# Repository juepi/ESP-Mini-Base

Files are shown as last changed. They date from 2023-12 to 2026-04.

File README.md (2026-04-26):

# ESP-Mini-Base
Base PCB ("hat") for ESP boards in WEMOS Mini format created with [KiCad EDA](https://www.kicad.org/). Primarily designed for [WEMOS S2 Mini](https://www.wemos.cc/en/latest/s2/s2_mini.html) and [D1 Mini](https://www.wemos.cc/en/latest/d1/d1_mini.html), might work for others / upcoming boards with a compatible pinout.  
The schematic describes the functionality and options in detail, it is also [available as PDF](pdf/ESP-Mini-Base_v1.0_schematic.pdf).

## Available functionality

The board provides the following functions:

* 3x N-Channel MOSFET drains (20A / 20Vds; no more than 5A recommended)
* 1x AC/DC SSR (48Vpp, 500mA max.)
* 1x Supply switch (5V or 3.3V, 2A max.)
* 2x 4-channel Level shifters to 5V
* 1x ADC attenuator with input selection (3V3 rail, 5V rail or external pin)
* 1x Pushbutton
* 3V3 and 5V I2C Pullups for default I2C pins of S2 and D1 Mini
* 5V LDO linear regulator for power supply up to 12V

The board has been designed in a way to allow you maximum flexibility. Every function needs to be enabled via solder jumpers on the bottom PCB side (for default wiring), or you may wire different IOs to the according pin headers on the board.  
The only exclusion are the 8 IOs wired to the 2 level shifters, which are hard wired and cannot be changed. The IOs have been selected to allow you level-shifted SPI or I2C for both S2 and D1 boards.

## Power Supply

There are several ways to power the board, the following table shows you the options and required configuration (solder jumpers on bottom PCB side):

| Powered by | Short Solder Jumpers | Notes |
| --- | --- | --- |
| 5V/VBUS Pin or USB Port | JP12 | Not recommended for MOSFET usage! At least connect GND wire to J9 if you try to do so|
| "12VDC" through J9 | JP12,JP13 | 5V generated from onboard regulator and supplied to ESP. Supported input voltage range: between 6.25 and 12V|
| 3.3VDC through J9 | none | Use to power ESP directly from LFP battery (in example)|

When powering the board from a LFP cell, you might want to have 5VDC (in example for a LED strip). Mainly for this reason, you have the ability to connect a Boost-converter board to J10. Short the Jumper JP11 and JP10 to 1-2 and you will be able to enable the Boost-converter via IO14 (U2 supply switch).  
Although the installed 5V LDO linear regulator supports up to 26V input voltage, no more than 12V are recommended due to the high power dissipation of the regulator.  

## Note on production data

The production data has been created for [JLCPCB assembly service](https://jlcpcb.com/) using the [Fabrication Toolkit Plugin](https://github.com/bennymeg/JLC-Plugin-for-KiCad). When placing an order, keep in mind that the rotation of several parts (MOSFETs, all ICs, C6) needs to be updated. Cross-check with the KiCAD Layout to verify that all parts will be placed correctly.

## Note on MOSFET usage

If you are switching a device through one of the 3 installed N-Channel MOSFETs, make sure that the switched device does **not have any reference to the input voltage GND** of the ESP-Mini-Base (in example through a data connection like I2C etc.). Chances are high to see magic smoke leaving your setup if you fail to use suitable galvanic isolation (beside the fact that the "switched" device probably won't power off at all)!
The MOSFETs have been tested fine with 5kHz PWM, so they should work for dimming RGB LED strips in example. Keep an eye on the overall current running through the FETs, more than 5A should be tested thoroughly before placing it into production.
  
## Pictures

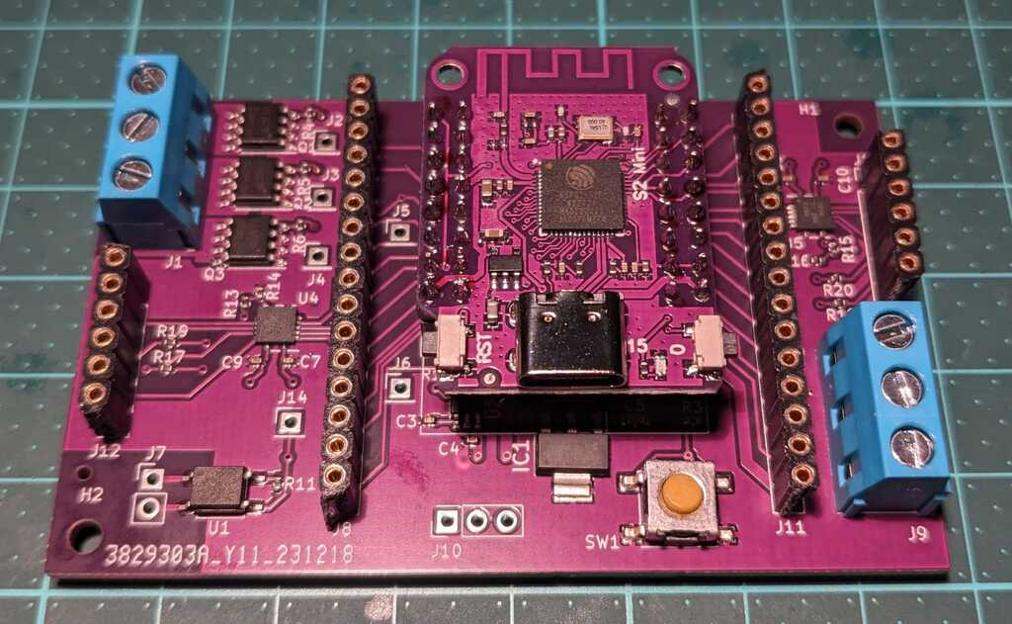
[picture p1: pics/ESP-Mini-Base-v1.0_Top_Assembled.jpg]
Assembled PCB, top side

Assembled ESP-Mini-Base v1.0 top side with S2 Mini  

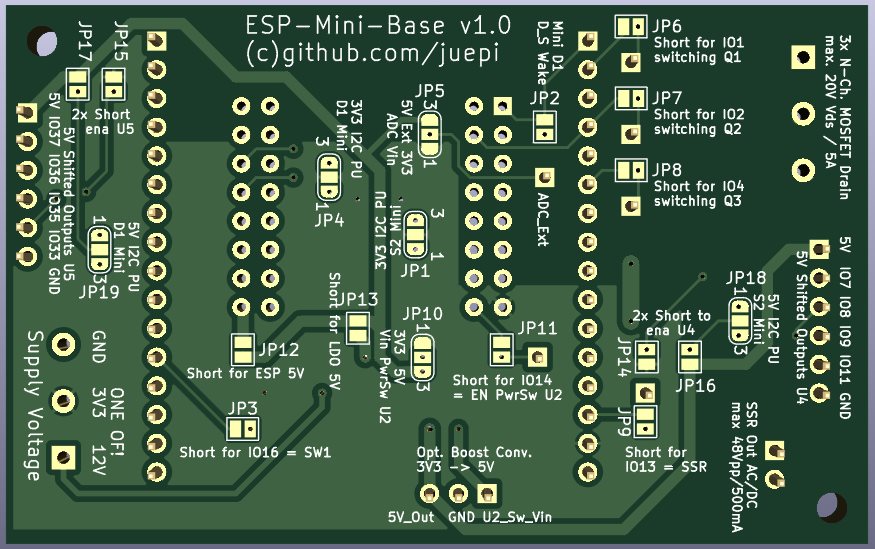
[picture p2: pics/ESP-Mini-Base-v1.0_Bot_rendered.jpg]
Rendered PCB, bottom side

Rendered view of the bottom side showing I/O and solder jumpers with descriptions.

**Note on I2C Pullup solder-jumpers (3,3 and 5V):** all 3 pins of the jumpers need to be connected with tin solder if you want to enable the pullups.

## ESPHome
Added sample ESPHome YAML config which uses most of the functionality provided by the ESP-Mini-Base. The sample is intended to be used with the `WEMOS S2 Mini` board.  
**Note on first wired flash:** The web based flashing with ESPHome did not work for me with the `WEMOS S2 Mini`. I had to download the compiled binary firmware and then used the [Adafruit WebSerial ESPTool](https://adafruit.github.io/Adafruit_WebSerial_ESPTool/) which managed to flash the ESP board correctly. Subsequent OTA updates worked perfectly well with ESPHome.

## Changelog

### v1.1
- Improved high current traces to MOSFETs
- Improved heat dissipation of LDO converter (IC1)
- Upgraded KiCAD files to version 8
- Set "remove from BoM" flag on all THT parts and solder jumpers

Have fun,  
Juergen

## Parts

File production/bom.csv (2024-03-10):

Designator | Footprint | Quantity | Value | LCSC Part #
C1, C10, C4, C7, C8, C9 | 0402 | 6 | 100n/25V | C106256
C2 | 0402 | 1 | 1µ/25V | C967571
C3 | 0402 | 1 | 1n/25V | C575438
C5 | 0603 | 1 | 470nF/50V | C77572
C6 | CP_EIA-7343-31_Kemet-D | 1 | 100µF/16V | C171666
H1, H2 | MountingHole_2.7mm_M2.5 | 2 | MountingHole
IC1 | SOT230P700X180-4N | 1 | LM2940IMP-5.0_NOPB | C13991
J1, J9 | TerminalBlock_RND_205-00046_1x03_P5.00mm_Horizontal | 2 | Screw_Terminal_01x03
J10 | PinHeader_1x03_P2.54mm_Vertical | 1 | Conn_01x03
J11, J8 | PinHeader_1x16_P2.54mm_Vertical | 2 | Conn_01x16
J12, J13 | PinHeader_1x06_P2.54mm_Vertical | 2 | Conn_01x06
J14, J2, J3, J4, J5, J6 | PinHeader_1x01_P2.54mm_Vertical | 6 | ~
J7 | PinHeader_1x02_P2.54mm_Vertical | 1 | Conn_01x02
JP1, JP10, JP18, JP19, JP4, JP5 | SolderJumper-3_P1.3mm_Open_RoundedPad1.0x1.5mm_NumberLabels | 6 | SolderJumper_3_Open
JP11, JP12, JP13, JP14, JP15, JP16, JP17, JP2, JP3, JP6, JP7, JP8, JP9 | SolderJumper-2_P1.3mm_Open_Pad1.0x1.5mm | 13
Q1, Q2, Q3 | SOIC-8_3.9x4.9mm_P1.27mm | 3 | AO4402G | C2931062
R1, R2, R7, R8 | 0402 | 4 | 3k3 | C965263
R10 | 0402 | 1 | 3k6/0.1% | C186338
R11 | 0402 | 1 | 220 | C102889
R12, R3, R4, R5, R6 | 0402 | 5 | 10k | C25744
R13, R15 | 0402 | 2 | 931 | C35293
R14, R16 | 0402 | 2 | 1k8 | C170383
R17, R18, R19, R20 | 0402 | 4 | 4k7 | C25900
R9 | 0402 | 1 | 12k/0.1% | C186350
SW1 | SW_Push_1P1T_NO_6x6mm_H9.5mm | 1 | SW_Omron_B3FS | C271751
U1 | SOP-4_3.8x4.1mm_P2.54mm | 1 | G3VM-61VY2 | C1558855
U2 | SOT-23-6 | 1 | TPS22918DBVR | C131941
U3 | WEMOS_S2_Mini | 1 | S2 Mini
U4, U5 | Texas_S-PVQFN-N14 | 2 | TXB0104RGY | C400708

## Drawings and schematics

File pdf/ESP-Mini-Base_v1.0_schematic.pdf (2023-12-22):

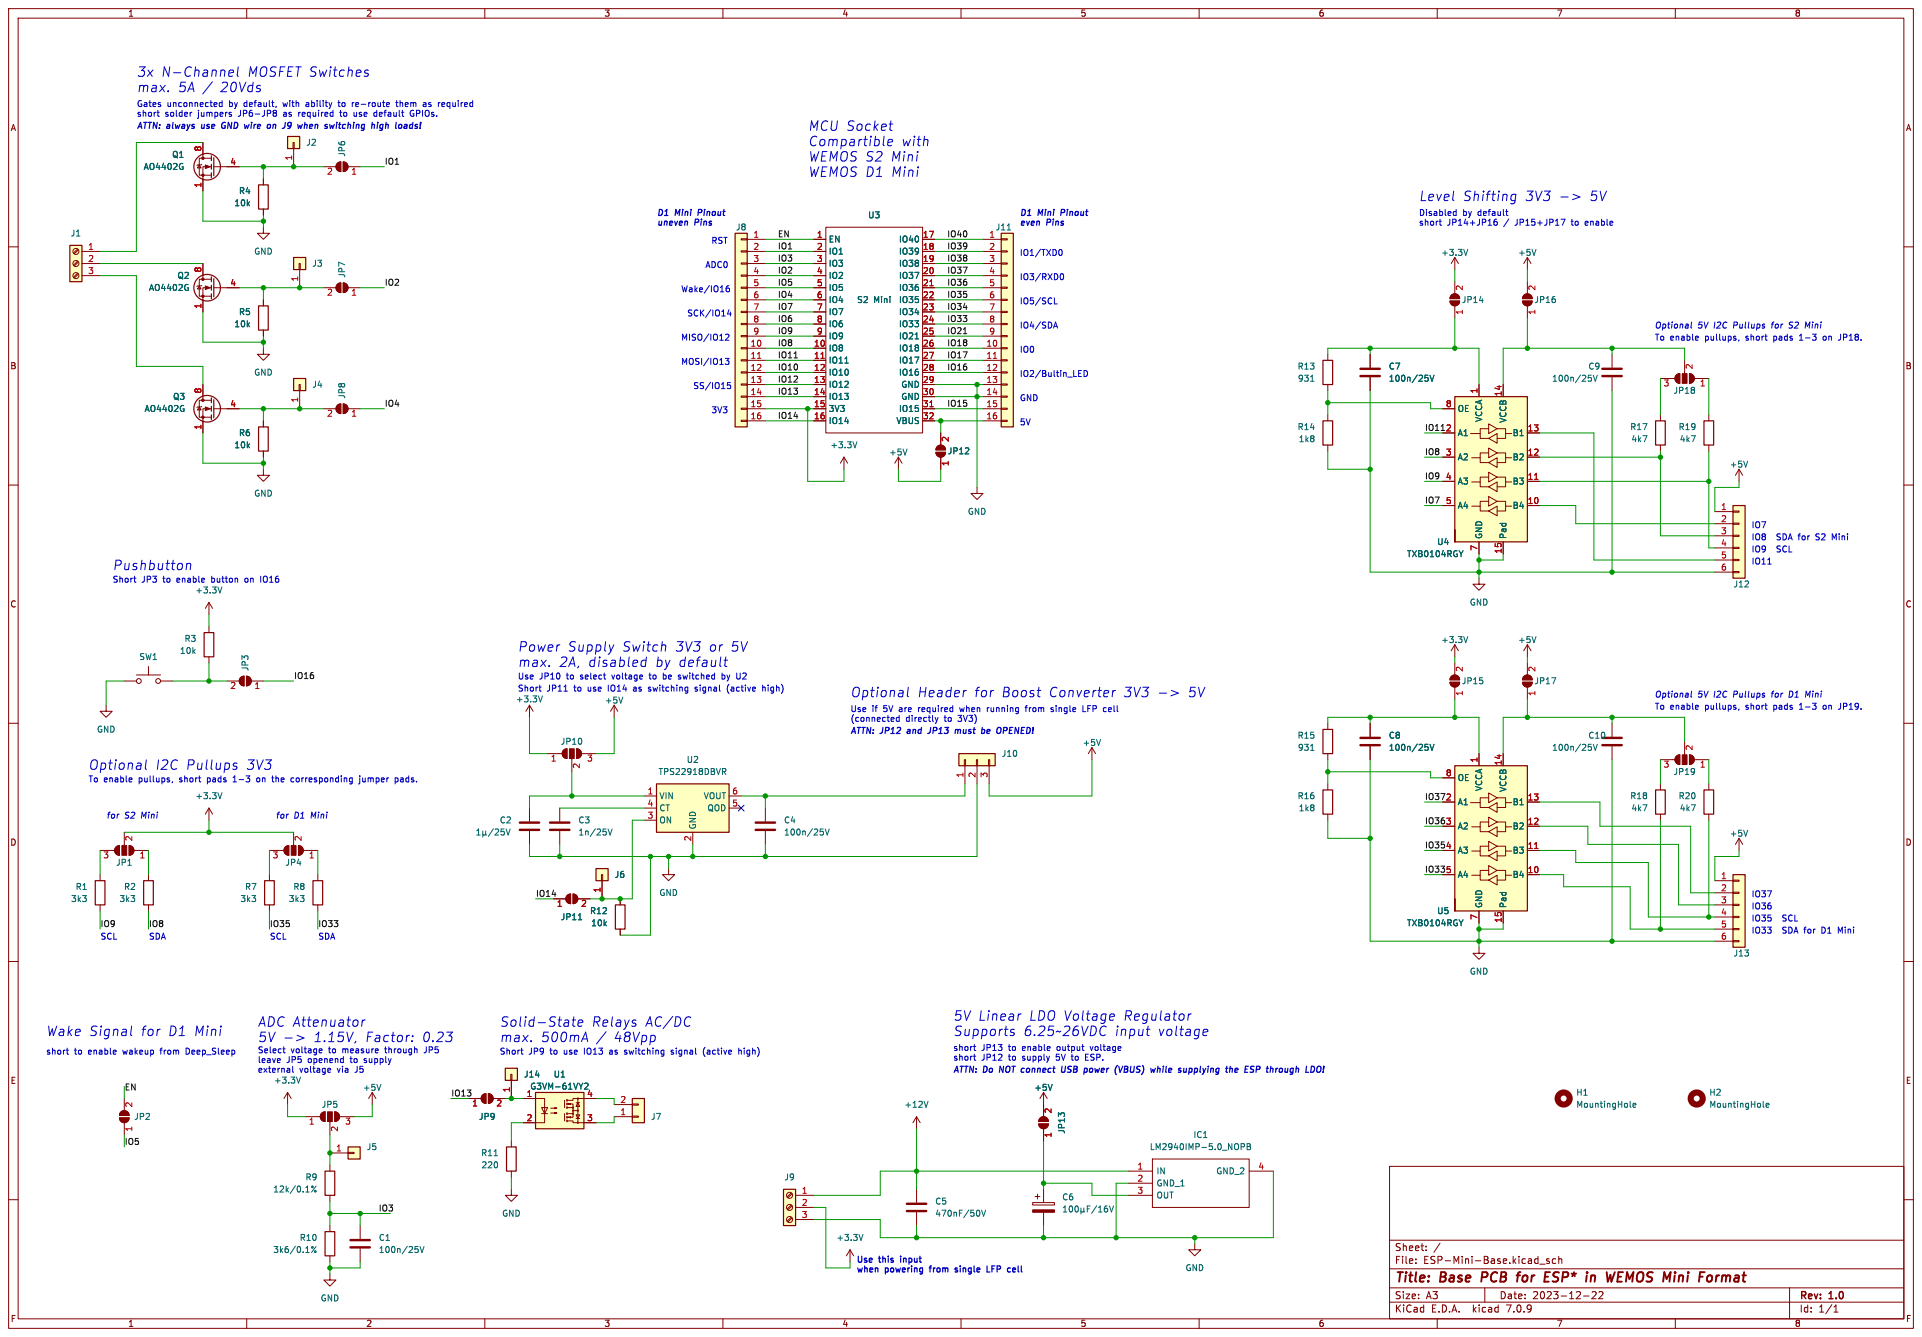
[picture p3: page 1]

ATTN: always use GND wire on J9 when switching high loads!

D1 Mini Pinout uneven Pins MISO/IO12 RST
ADC0 MOSI/IO13 Wake/IO16 SCK/IO14

for D1 Mini Optional I2C Pullups 3V3

2 ON 3 CT 4 QOD 5 VOUT 6 U2 TPS22918DBVR

short JP12 to supply 5V to ESP. 5V Linear LDO Voltage Regulator
Supports 6.25~26VDC input voltage

Select voltage to measure through JP5

Use this input when powering from single LFP cell

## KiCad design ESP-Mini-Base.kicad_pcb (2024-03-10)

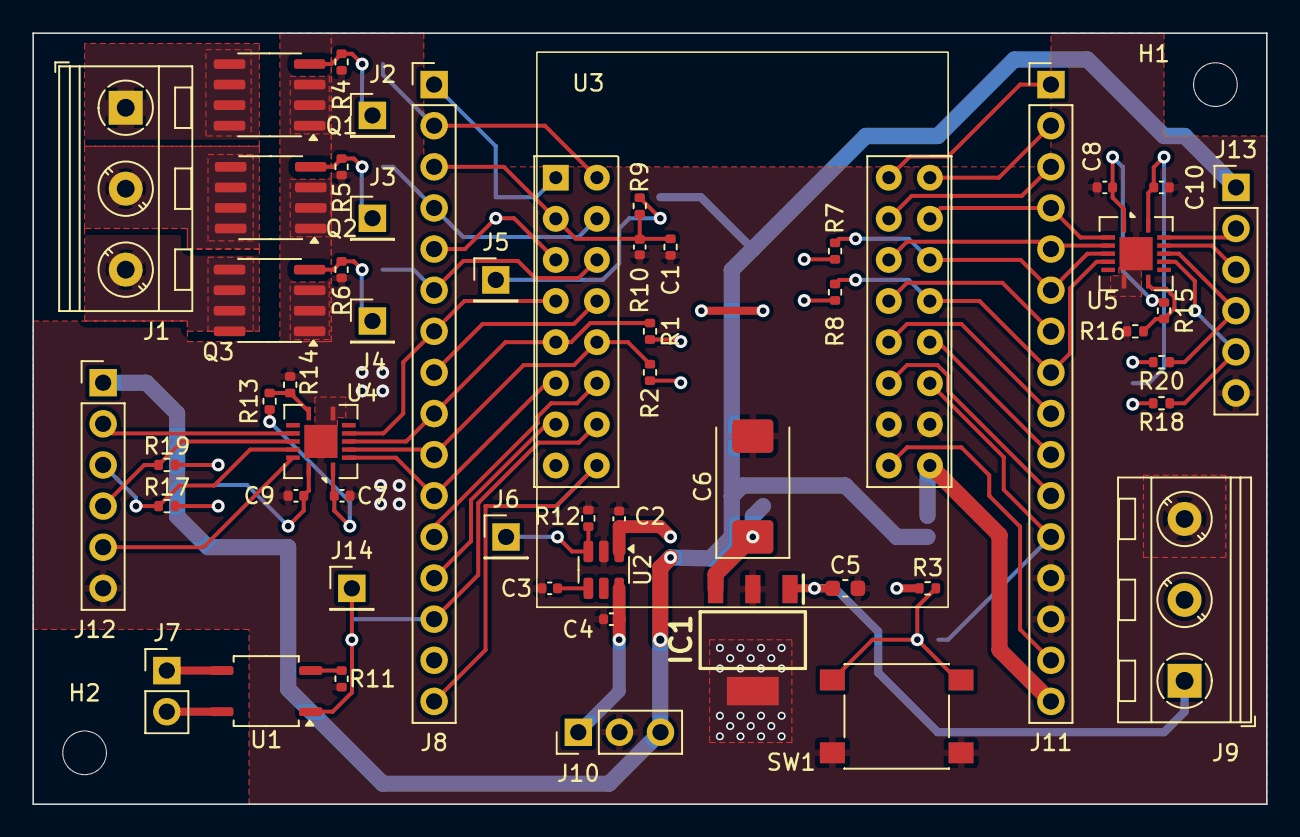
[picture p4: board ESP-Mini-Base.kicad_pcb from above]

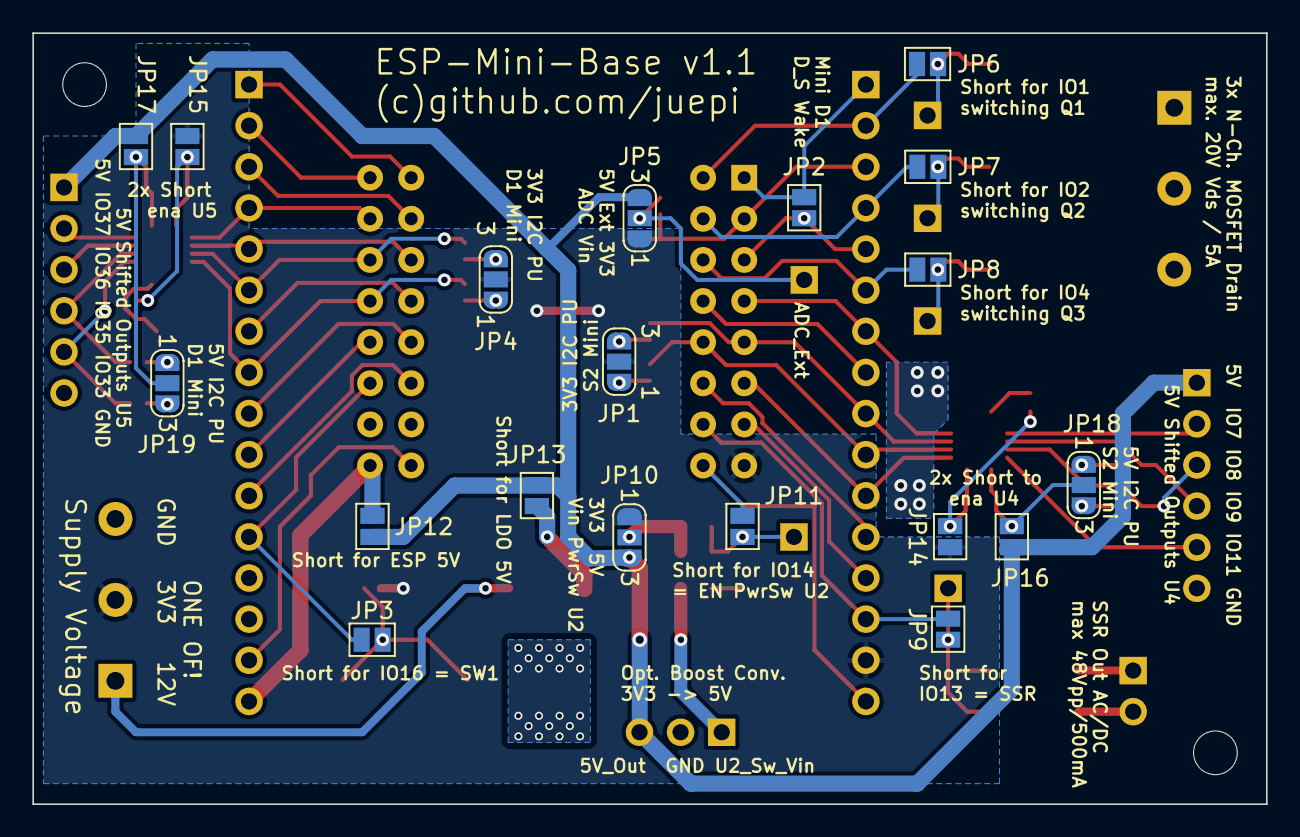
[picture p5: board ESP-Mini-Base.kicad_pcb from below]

Board: 2 copper layers, 76.2 x 47.6 mm, 75 parts (19 on the bottom side), 72 nets.

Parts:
C1, C4, C7, C8, C9, C10: 100n/25V; C_0402_1005Metric
C2: 1µ/25V; C_0402_1005Metric
C3: 1n/25V; C_0402_1005Metric
C5: 470nF/50V; C_0603_1608Metric
C6: 100µF/16V; CP_EIA-7343-31_Kemet-D
H1, H2: MountingHole; MountingHole_2.7mm_M2.5
IC1: LM2940IMP-5.0_NOPB; SOT230P700X180-4N
J1, J9: Screw_Terminal_01x03; TerminalBlock_RND_205-00046_1x03_P5.00mm_Horizontal
J2, J3, J4, J5, J6, J14: PinHeader_1x01_P2.54mm_Vertical
J7: Conn_01x02; PinHeader_1x02_P2.54mm_Vertical
J8, J11: Conn_01x16; PinHeader_1x16_P2.54mm_Vertical
J10: Conn_01x03; PinHeader_1x03_P2.54mm_Vertical
J12, J13: Conn_01x06; PinHeader_1x06_P2.54mm_Vertical
JP1, JP4, JP5, JP10, JP18, JP19: SolderJumper_3_Open; SolderJumper-3_P1.3mm_Open_RoundedPad1.0x1.5mm_NumberLabels
JP2, JP3, JP6, JP7, JP8, JP9, JP11, JP12, JP13, JP14, JP15, JP16, JP17: SolderJumper-2_P1.3mm_Open_Pad1.0x1.5mm
Q1, Q2, Q3: AO4402G; SOIC-8_3.9x4.9mm_P1.27mm
R1, R2, R7, R8: 3k3; R_0402_1005Metric
R3, R4, R5, R6, R12: 10k; R_0402_1005Metric
R9: 12k/0.1%; R_0402_1005Metric
R10: 3k6/0.1%; R_0402_1005Metric
R11: 220; R_0402_1005Metric
R13, R15: 931; R_0402_1005Metric
R14, R16: 1k8; R_0402_1005Metric
R17, R18, R19, R20: 4k7; R_0402_1005Metric
SW1: SW_Omron_B3FS; SW_Push_1P1T_NO_6x6mm_H9.5mm
U1: G3VM-61VY2; SOP-4_3.8x4.1mm_P2.54mm
U2: TPS22918DBVR; SOT-23-6
U3: S2 Mini; WEMOS_S2_Mini
U4, U5: TXB0104RGY; Texas_S-PVQFN-N14

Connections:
+3.3V: J8.15, J9.2, JP1.2 (C), JP4.2 (C), JP5.1 (A), JP10.1 (A), JP14.2 (B), JP15.2 (B), R3.2, U3.15 (3V3)
+5V: J10.3, J12.1, J13.1, JP5.3 (B), JP10.3 (B), JP12.1 (A), JP13.2 (B), JP16.2 (B), JP17.2 (B)
+12V: C5.1, IC1.1 (IN), J9.1
/EN: J8.1, JP2.2 (B), U3.1 (EN)
/IO1: J8.2, JP6.1 (A), U3.2 (IO1)
/IO2: J8.4, JP7.1 (A), U3.4 (IO2)
/IO3: C1.1, J8.3, R9.1, R10.2, U3.3 (IO3)
/IO4: J8.6, JP8.1 (A), U3.6 (IO4)
/IO5: J8.5, JP2.1 (A), U3.5 (IO5)
/IO6: J8.8, U3.8 (IO6)
/IO7: J8.7, U3.7 (IO7), U4.5 (A4)
/IO8: J8.10, R2.1, U3.10 (IO8), U4.3 (A2)
/IO9: J8.9, R1.1, U3.9 (IO9), U4.4 (A3)
/IO10: J8.12, U3.12 (IO10)
/IO11: J8.11, U3.11 (IO11), U4.2 (A1)
/IO12: J8.13, U3.13 (IO12)
/IO13: J8.14, JP9.1 (A), U3.14 (IO13)
/IO14: J8.16, JP11.1 (A), U3.16 (IO14)
/IO15: J11.15, U3.31 (IO15)
/IO16: J11.12, JP3.1 (A), U3.28 (IO16)
/IO17: J11.11, U3.27 (IO17)
/IO18: J11.10, U3.26 (IO18)
/IO21: J11.9, U3.25 (IO21)
/IO33: J11.8, R8.1, U3.24 (IO33), U5.5 (A4)
/IO34: J11.7, U3.23 (IO34)
/IO35: J11.6, R7.1, U3.22 (IO35), U5.4 (A3)
/IO36: J11.5, U3.21 (IO36), U5.3 (A2)
/IO37: J11.4, U3.20 (IO37), U5.2 (A1)
/IO38: J11.3, U3.19 (IO38)
/IO39: J11.2, U3.18 (IO39)
/IO40: J11.1, U3.17 (IO40)
GND: C1.2, C2.2, C3.2, C4.2, C5.2, C6.2, C7.2, C8.2, C9.2, C10.2, IC1.2 (GND_1), IC1.4 (GND_2), J9.3, J10.2, J11.13, J11.14, J12.6, J13.6, Q1.1 (S), Q1.2 (S), Q1.3 (S), Q2.1 (S), Q2.2 (S), Q2.3 (S), Q3.1 (S), Q3.2 (S), Q3.3 (S), R4.1, R5.1, R6.1, R10.1, R11.1, R12.1, R14.1, R16.1, SW1.1, U2.2 (GND), U3.29 (GND), U3.30 (GND), U4.7 (GND), U4.15 (Pad), U5.7 (GND), U5.15 (Pad)
unnamed: C6.1, IC1.3 (OUT), JP13.1 (A)
unnamed: J1.1, Q1.5 (D), Q1.6 (D), Q1.7 (D), Q1.8 (D)
unnamed: J1.2, Q2.5 (D), Q2.6 (D), Q2.7 (D), Q2.8 (D)
unnamed: J1.3, Q3.5 (D), Q3.6 (D), Q3.7 (D), Q3.8 (D)
unnamed: J2.1, JP6.2 (B), Q1.4 (G), R4.2
unnamed: J3.1, JP7.2 (B), Q2.4 (G), R5.2
unnamed: J4.1, JP8.2 (B), Q3.4 (G), R6.2
unnamed: J5.1, JP5.2 (C), R9.2
unnamed: J6.1, JP11.2 (B), R12.2, U2.3 (ON)
unnamed: J7.1, U1.3
unnamed: J7.2, U1.4
unnamed: C4.1, J10.1, U2.6 (VOUT)
unnamed: J11.16, JP12.2 (B), U3.32 (VBUS)
unnamed: J12.2, U4.10 (B4)
unnamed: J12.3, R17.1, U4.12 (B2)
unnamed: J12.4, R19.1, U4.11 (B3)
unnamed: J12.5, U4.13 (B1)
unnamed: J13.2, U5.13 (B1)
unnamed: J13.3, U5.12 (B2)
unnamed: J13.4, R20.1, U5.11 (B3)
unnamed: J13.5, R18.1, U5.10 (B4)
unnamed: J14.1, JP9.2 (B), U1.1
unnamed: JP1.1 (A), R2.2
unnamed: JP1.3 (B), R1.2
unnamed: JP3.2 (B), R3.1, SW1.2
unnamed: JP4.1 (A), R8.2
unnamed: JP4.3 (B), R7.2
unnamed: C2.1, JP10.2 (C), U2.1 (VIN)
unnamed: C7.1, JP14.1 (A), R13.2, U4.1 (VCCA)
unnamed: C8.1, JP15.1 (A), R15.2, U5.1 (VCCA)
unnamed: C9.1, JP16.1 (A), JP18.2 (C), U4.14 (VCCB)
unnamed: C10.1, JP17.1 (A), JP19.2 (C), U5.14 (VCCB)
unnamed: JP18.1 (A), R19.2
unnamed: JP18.3 (B), R17.2
unnamed: JP19.1 (A), R20.2
unnamed: JP19.3 (B), R18.2
unnamed: R11.2, U1.2
unnamed: C3.1, U2.4 (CT)
unnamed: R13.1, R14.2, U4.8 (OE)
unnamed: R15.1, R16.2, U5.8 (OE)

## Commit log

2023-12-22 update readme, pictures, schematic usage notes and pdf
    [ESP-Mini-Base.kicad_sch]
2023-12-22 fixed typo
    [ESP-Mini-Base.kicad_sch]
2024-03-10 minor improvements; updated to KiCAD 8
    [ESP-Mini-Base.kicad_pcb, ESP-Mini-Base.kicad_sch, bom.csv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]
2026-04-26 update readme on wired ESPHome flashing
